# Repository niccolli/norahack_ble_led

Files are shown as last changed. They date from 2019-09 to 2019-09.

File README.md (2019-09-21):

# 野良HACK BLE〜LEDブリッジ基板

[技術書典7 け27D](https://techbookfest.org/event/tbf07/circle/5663970140618752) にて頒布するBLE〜LEDブリッジ基板の製造データです。

## 各種制御ソフトウェア

- [M5Stack用](https://github.com/da-eee/CNoraBLE)
- [FirebaseとEnebular](https://github.com/muramasa2764/ESP32Firebase-BLE)
- [Web Bluetoothデモ](https://pokiiio.github.io/Jones/)

## 製造データ

### 回路図

output/Schematic.pdf をお読みください。

### ガーバー

output/Gerberフォルダ内を参照ください。

参考までに、[FusionPCB](https://www.seeedstudio.com/fusion.html)に発注した際の設定を記載します。

- PCB Dimension - 32mm*32mm 
- Impedance Control - No 
- Surface Finish - Hasl(Lead Free) 
- Min Solder Mask Dam - 0.4mm↑ 
- Copper Weight - 1oz. 
- Half-cut / Castellated Holes - No 
- Min Hole Size - 0.3mm 
- PCB Color - Green 
- Material - FR4 TG130 
- Layer - 2 
- PCB Qty. - 50 
- Blind Vias - No 
- PCB Thickness - 1.6mm 
- Min Tracking / Spacing - 6/6mil 
- Panelized PCBs - 1 
- Expedited Option - No 

### 部品表

[こちら](https://docs.google.com/spreadsheets/d/1IFBm3dJIjSWrcvgrVqms4TnD1tUxHpUHN8ivpyQduAM/edit?usp=sharing)を参照ください。

## 基板取り扱いの諸注意

### 電池・電源について

- 乾電池は4本以上直列に接続しないでください。BLEマイコンに供給するLDOの最大定格が6Vのため、4本以上接続すると電源が故障します。
- 乾電池が2本ではLEDが点灯しません。ただし、LEDを接続せずBLEマイコンのみ使用する場合は2本でも問題ありません。

### ファームウェアの書き込みについて

J2またはJ3にピンをはんだづけすることで、BLEモジュールのファームウェアを書き換えることができます。

J-LINK EDUやLiteを使用する場合はJ3、STMicroのNucleoボードのST-LINKを書き換えて使う場合はJ2が便利です。どちらも結線は同じですので、用途に合わせてお選びください。

### シリアル通信について

基板裏面にシリアル通信用のパッドを引き伸ばしています。もちろんGPIOとしても使えますので、是非ご活用ください。

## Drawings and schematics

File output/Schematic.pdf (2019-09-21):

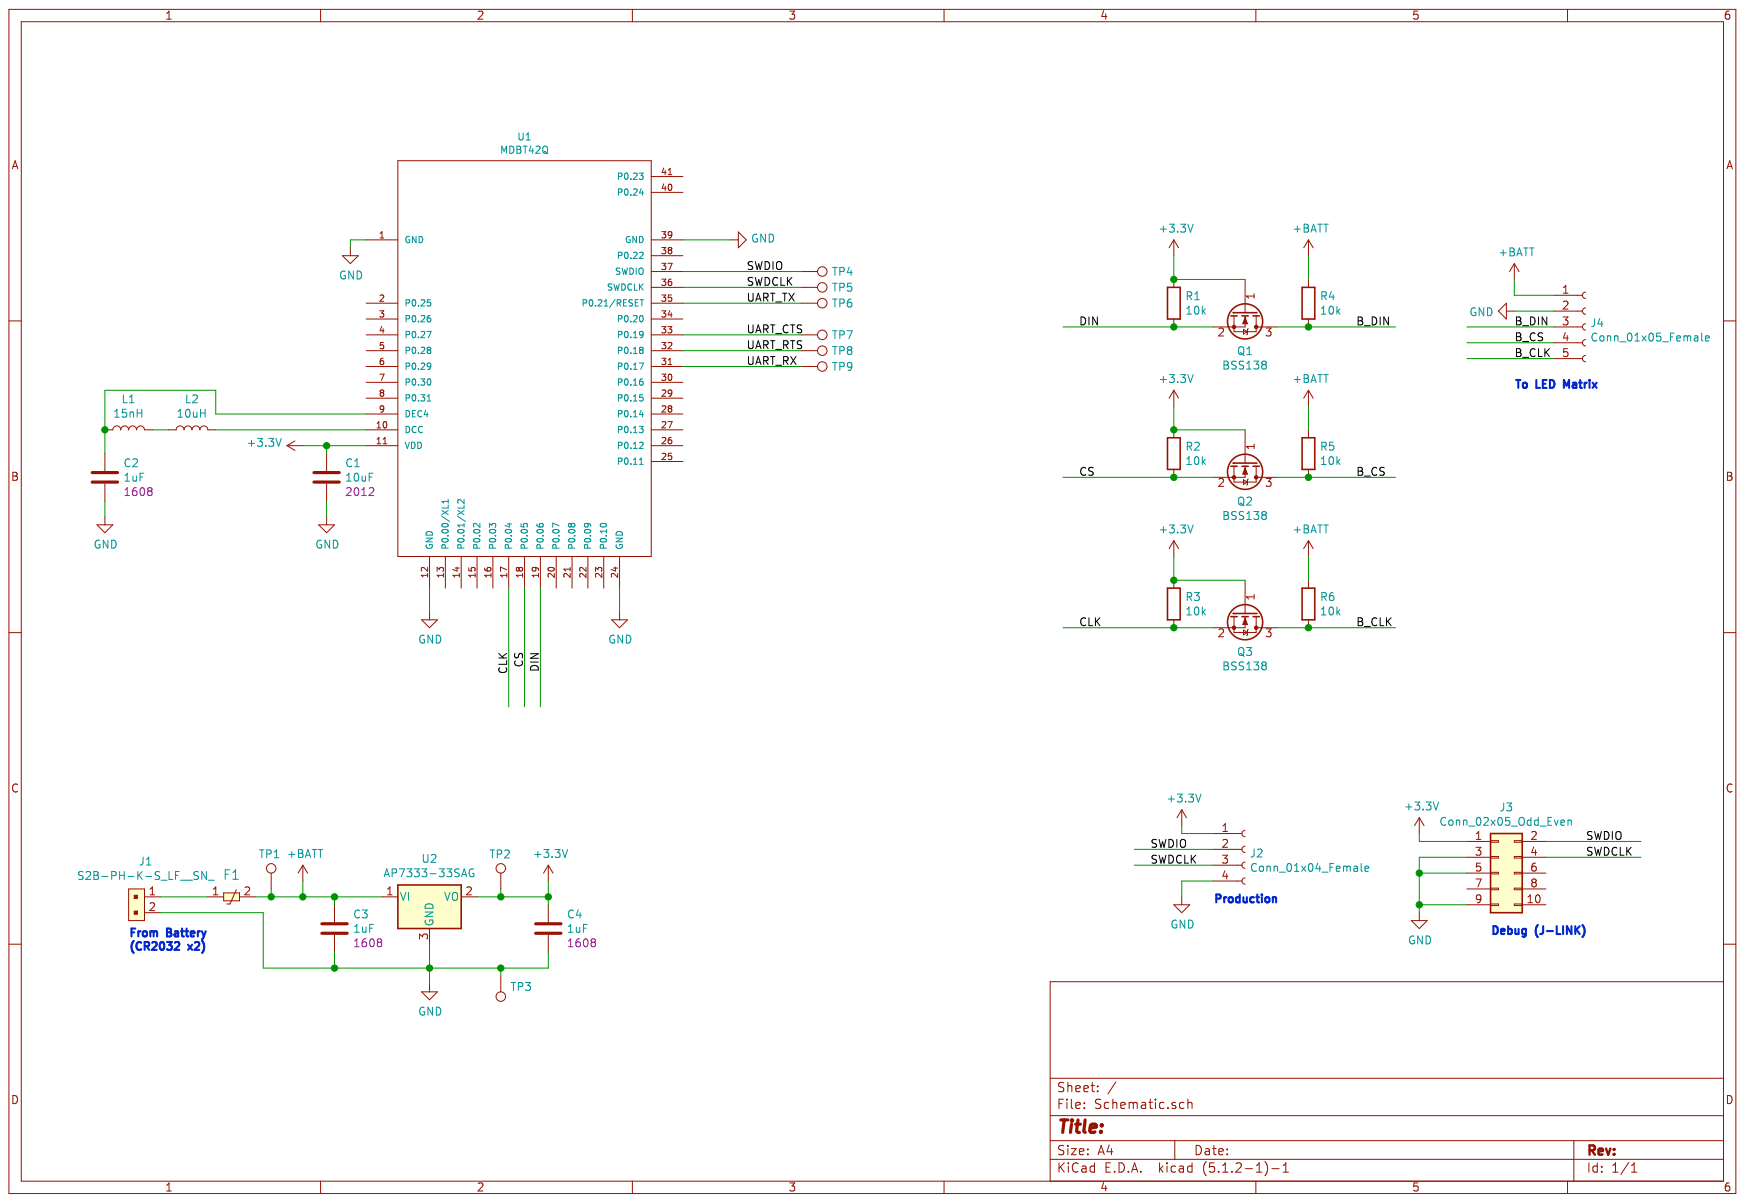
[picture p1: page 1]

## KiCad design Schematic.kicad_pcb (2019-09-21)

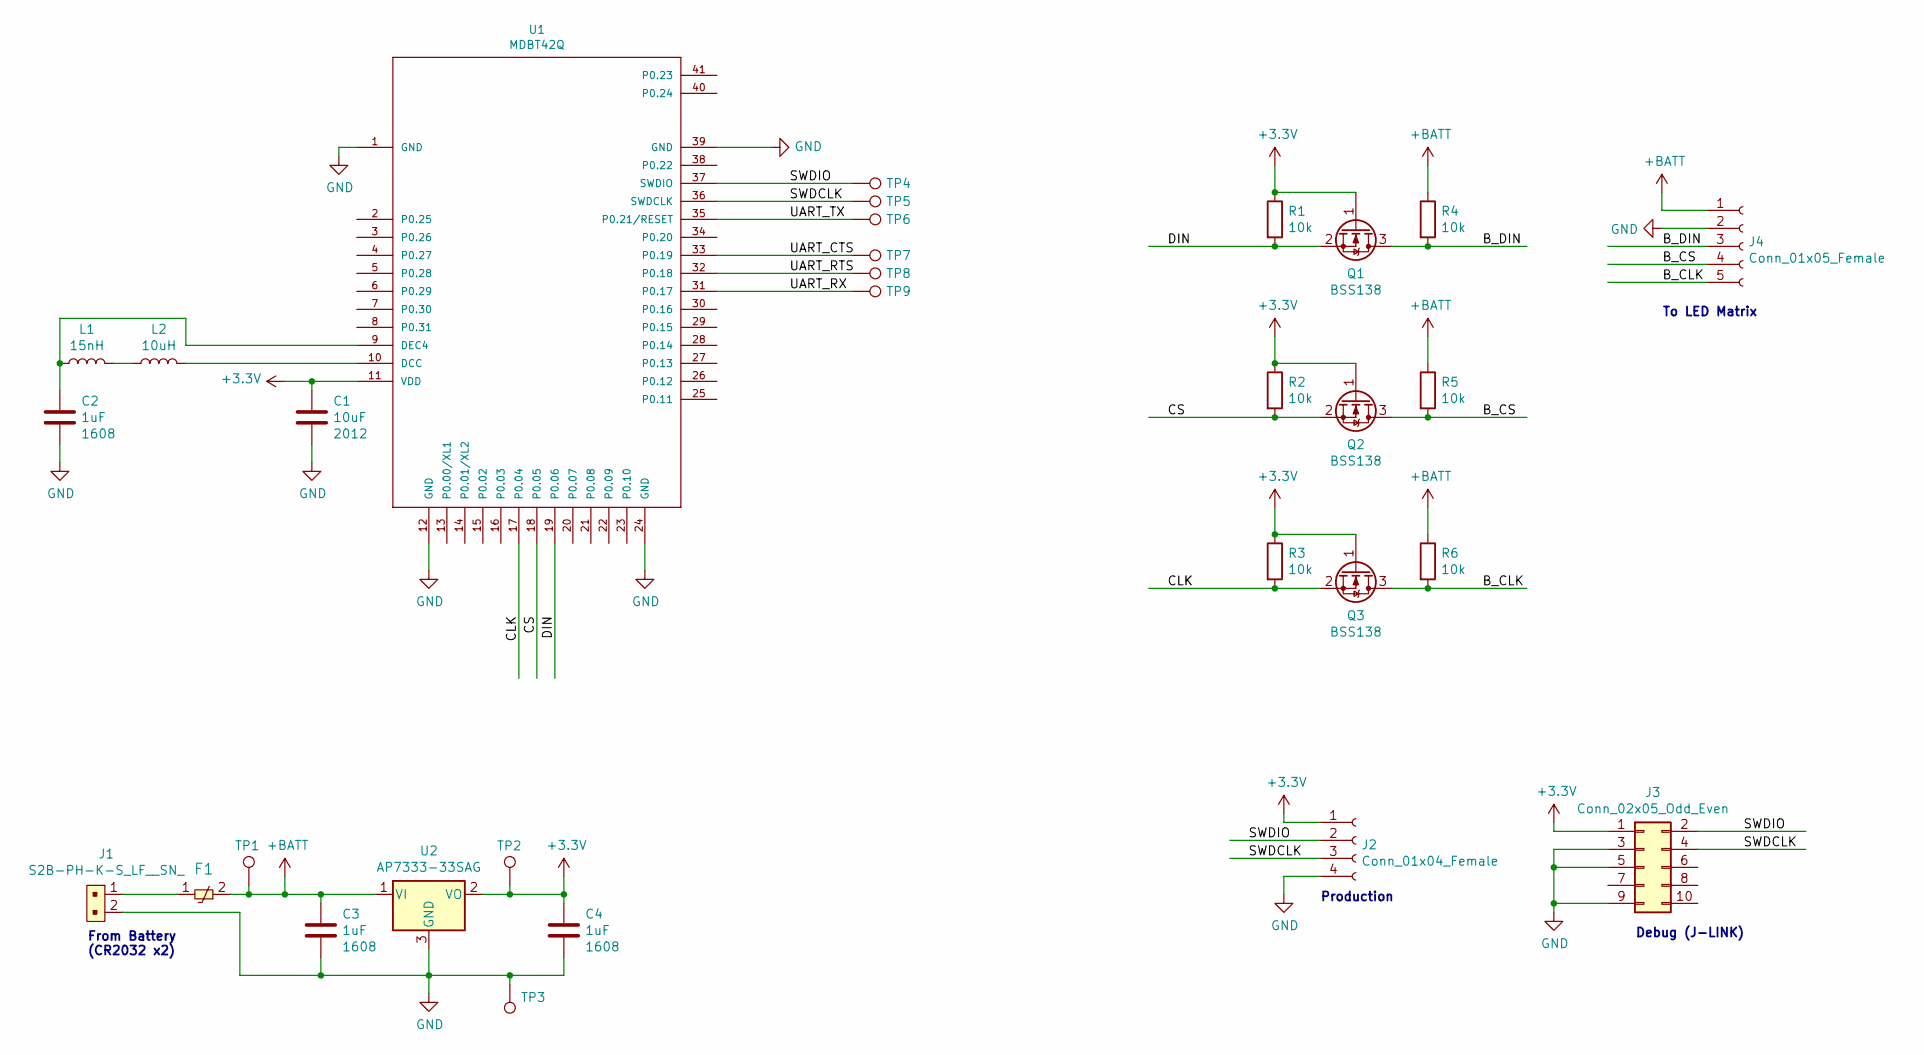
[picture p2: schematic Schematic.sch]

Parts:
C1: 10uF; C_0805_2012Metric_Pad1.15x1.40mm_HandSolder
C2, C3, C4: 1uF; C_0603_1608Metric_Pad1.05x0.95mm_HandSolder
F1: FEMTOSMDC010F-02; Fuse_0603_1608Metric_Pad1.05x0.95mm_HandSolder; MPN AS32 2R025
J1: S2B-PH-K-S_LF__SN_; PinHeader_1x2_P2mm_Drill1mm_RA; MPN S2B-PH-K-S(LF)(SN); Digi-Key_PN 455-1719-ND
J2: Conn_01x04_Female; PinHeader_1x04_P2.54mm_Vertical
J3: Conn_02x05_Odd_Even; PinHeader_2x05_P1.27mm_Vertical_SMD
J4: Conn_01x05_Female; PinHeader_1x05_P2.54mm_Horizontal
L1: 15nH; L_0603_1608Metric_Pad1.05x0.95mm_HandSolder; PartName HK160815NJ-T
L2: 10uH; L_0805_2012Metric_Pad1.15x1.40mm_HandSolder; PartName LBR2012T100K
Q1, Q2, Q3: BSS138; SOT-23
R1, R2, R3, R4, R5, R6: 10k; R_0603_1608Metric_Pad1.05x0.95mm_HandSolder
TP1, TP2, TP3, TP4, TP5, TP6, TP7, TP8, TP9: TestPoint; TestPoint_Pad_D1.5mm
U1: MDBT42Q
U2: AP7333-33SAG; SOT-23

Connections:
+3V3: C1.1, C4.1, J2.1, J3.1, Q1.1 (G), Q2.1 (G), Q3.1 (G), R1.1, R2.1, R3.1, TP2.1, U1.11 (VDD), U2.2 (VO)
+BATT: C3.1, F1.2, J4.1, R4.1, R5.1, R6.1, TP1.1, U2.1 (VI)
/B_CLK: J4.5, Q3.3 (D), R6.2
/B_CS: J4.4, Q2.3 (D), R5.2
/B_DIN: J4.3, Q1.3 (D), R4.2
/CLK: Q3.2 (S), R3.2, U1.17 (P0.04)
/CS: Q2.2 (S), R2.2, U1.18 (P0.05)
/DIN: Q1.2 (S), R1.2, U1.19 (P0.06)
/SWDCLK: J2.3, J3.4, TP5.1, U1.36 (SWDCLK)
/SWDIO: J2.2, J3.2, TP4.1, U1.37 (SWDIO)
/UART_CTS: TP7.1, U1.33 (P0.19)
/UART_RTS: TP8.1, U1.32 (P0.18)
/UART_RX: TP9.1, U1.31 (P0.17)
/UART_TX: TP6.1, U1.35 (P0.21/RESET)
GND: C1.2, C2.2, C3.2, C4.2, J1.2, J2.4, J3.3, J3.5, J3.9, J4.2, TP3.1, U1.1 (GND), U1.12 (GND), U1.24 (GND), U1.39 (GND), U2.3 (GND)
unnamed: C2.1, L1.1, U1.9 (DEC4)
unnamed: F1.1, J1.1
unnamed: L1.2, L2.1
unnamed: L2.2, U1.10 (DCC)

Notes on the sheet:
To LED Matrix
Debug (J-LINK)
Production
From Battery (CR2032 x2)

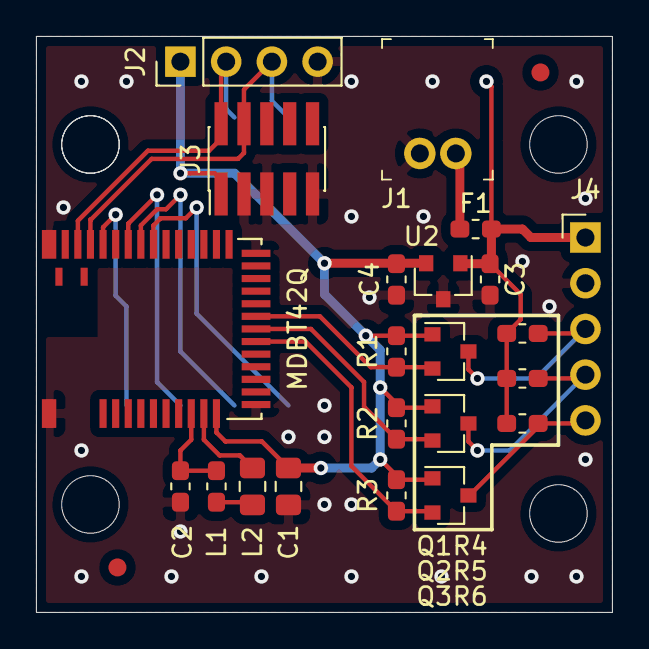
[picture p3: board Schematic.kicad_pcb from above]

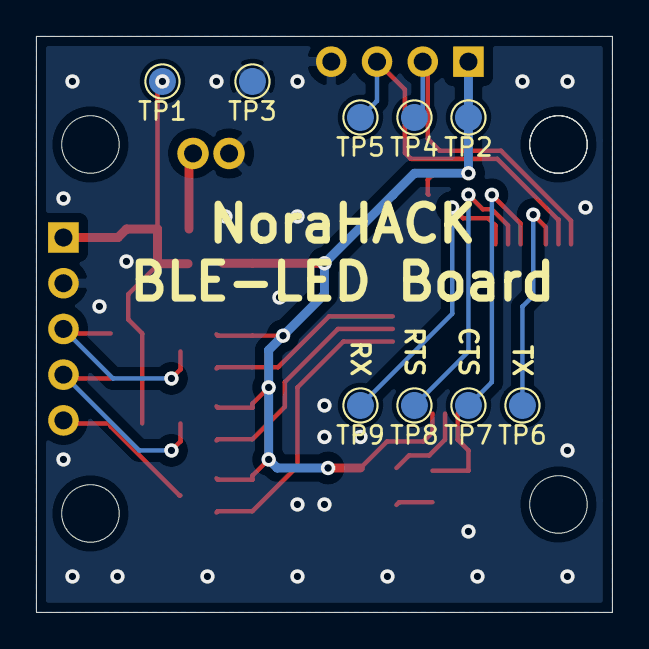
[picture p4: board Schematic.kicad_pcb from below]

Board: 2 copper layers, 32.0 x 32.0 mm, 31 parts (9 on the bottom side), 19 nets.

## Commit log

2019-08-25 Added schematic PDF
2019-09-21 TP等を追加
    [Schematic.kicad_pcb, Schematic.sch]
2019-09-21 回路図とガーバーを出力
    [Schematic-B_Cu.gbl, Schematic-B_Mask.gbs, Schematic-B_Paste.gbp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]
2019-09-21 ガーバーと回路図の区別がわかりにくかったので対処
    [Schematic-B_Cu.gbl, Schematic-B_Mask.gbs, Schematic-B_Paste.gbp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]
2019-09-21 .gitignoreを設定し、不要なファイルを削除。
2019-09-21 READMEの初稿を投稿
2019-09-21 制御ソフトのリンクを追加
